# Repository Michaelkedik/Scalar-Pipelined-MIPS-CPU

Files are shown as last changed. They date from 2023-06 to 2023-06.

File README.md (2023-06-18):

# Scalar Pipelined MIPS CPU Architecture

In this project I designed a Scalar Pipelined MIPS CPU that was executed on an altera board.
The CPU Core is capable of performing a variety of instructions from a given MIPS instruction set.
The architecture includes a MIPS ISA compatible CPU with data and program memory for hosting data and code and a standard MIPS register file. 
The top level and the MIPS core are structural and a single clock is used in the design.
In addition, the architecture includes hazard detection unit, forwarding unit, flushing and a single delay slot support.  
The figure below illustrates the design.  



## Description

The repositories in this project serve the following purposes:

**VHDL:** This repository contains VHDL codes for the top entity and components. These codes can be compiled using ModelSim and Quartus.

**DOC:** This repository contains project documentation and a README file that provides an explanation of the VHDL files' purpose.

**CODE:** This repository contains assembly code used for verifying the design's functionality.

**TB:** This repository contains Testbench files that were used for ModelSim verification of the design.

**SIM:** This repository contains ".do" files used for ModelSim simulation.

**QUARTUS:** This repository contains project files such as ".sof," SDC, and STP files, which are used for Quartus compilation and verification of the design.

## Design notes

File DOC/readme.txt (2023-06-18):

1)MIPS - The top entity, Synchronizes all the other components
2)IFETCH - Get the instruction and advance the PC according to the relevant adress
3)IDECODE - Decode the instruction and read and write from the register file
4)DMEMORY- Read or write from the data memory
5)EXECUTE- Performs all the logic or arithmetic actions
6)CONTROL - Produces the control signals that are needed for the instructions to be executed
7)HDU - Hazard Detection Unit, Detects dependencies between instructions and raise a stall signal when needed
8)FU - Forwarding Unit, Detects when forwarding is needed and raises control signals that are needed to decide which data will be used
	   in the ALU

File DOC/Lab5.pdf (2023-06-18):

# מעבדת ארכיטקטורת מעבדים מתקדמת ומאיצי חומרה

# דו"ח מעבדה 5

# מיכאל קדיק 316645415 עמית ניסני 205664345

## תיאור המ עבדה

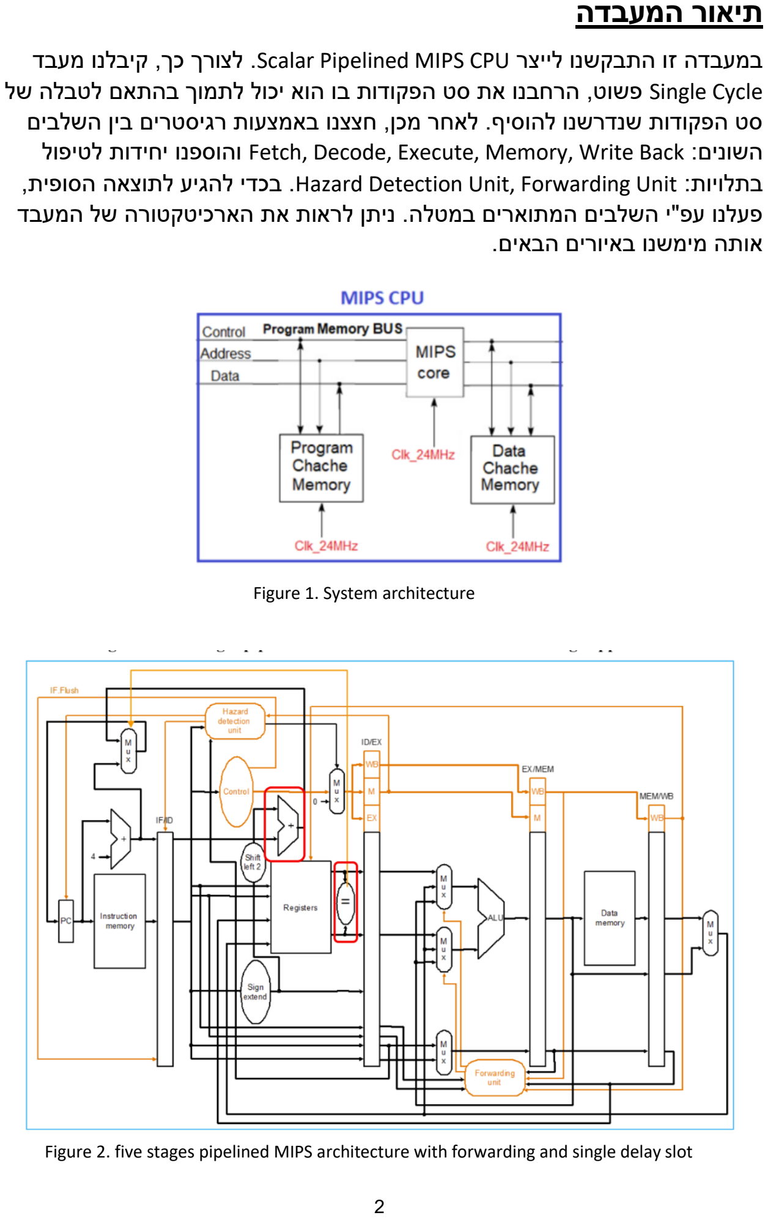
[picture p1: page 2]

במעבדה זו התבקשנו לייצר CPU MIPS Pipelined Scalar. לצורך כך, קיבלנו מעבד Cycle Single פשוט, הרחבנו את סט הפקודות בו הוא יכול לתמוך בהתאם לטבלה של סט הפקודות שנדרשנו להוסיף. לאחר מכן, חצצנו באמצעות רגיסטרים בין השלבים
לטיפול | ות | יחיד | והוספנו | Fetch, Decode, Execute, Memory, Write Back : | השונים
בתלויות: Unit Forwarding ,Unit Detection Hazard. בכדי להגיע לתוצאה הסופית, פעלנו עפ"י השלבים המתוארים במטלה. ניתן לראות את הארכיטקטורה של המעבד אותה מימשנו באיורים הבאים.

Figure 1. System architecture

Figure 2. five stages pipelined MIPS architecture with forwarding and single delay slot

כמו כן, הוספנו במעטפת החיצונית יציאות בכדי שנוכל לעקוב אחרי התוכנית באופן הבא:

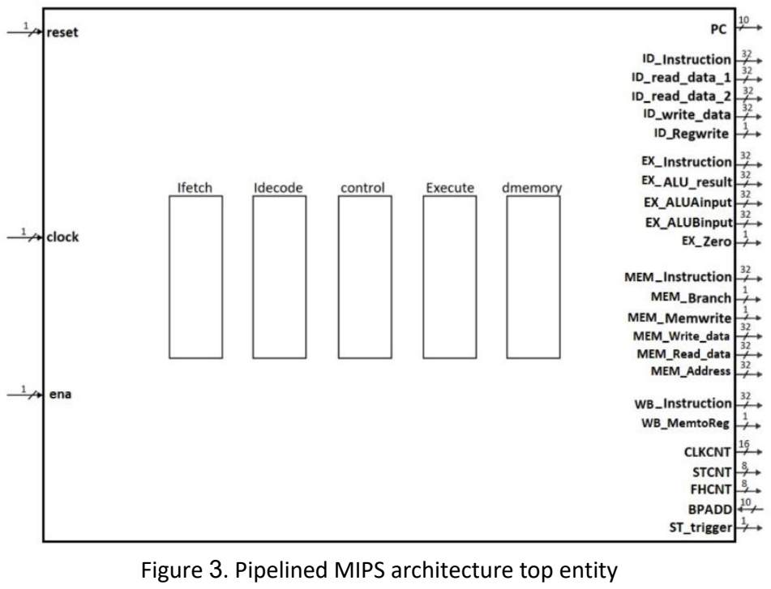
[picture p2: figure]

בכדי ליצור את המעבד המצוין למעלה, השתמשנו ברכיבי חומרה עליהם נפרט באיורים הבאים.

Figure 3. Pipelined MIPS architecture top entity

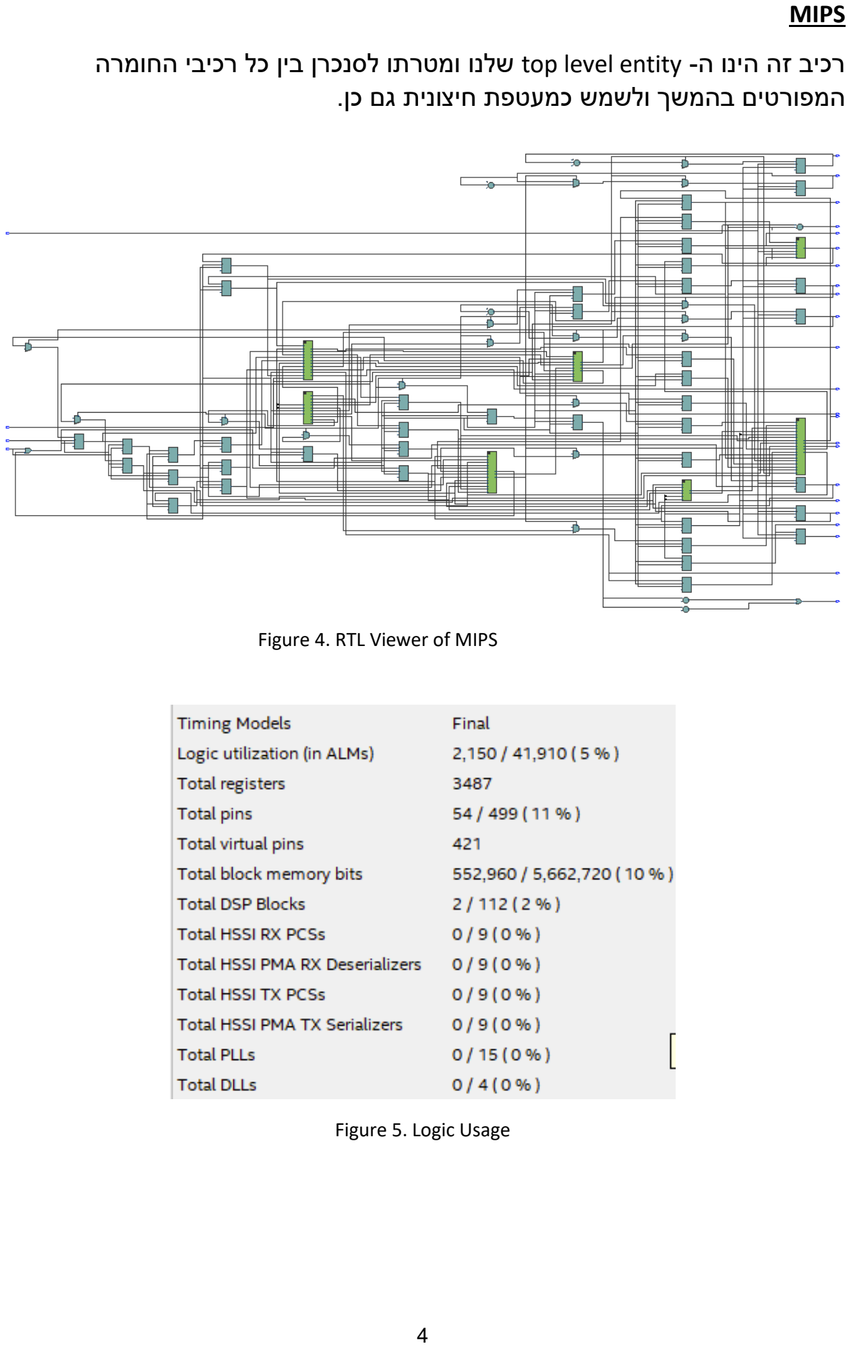
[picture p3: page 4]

MIPS

רכיב זה הינו ה- entity level top שלנו ומטרתו לסנכרן בין כל רכיבי החומרה המפורטים בהמשך ולשמש כמעטפת חיצונית גם כן.

Figure 4. RTL Viewer of MIPS

Figure 5. Logic Usage

IFETCH

תפקידו של רכיב זה הוא להביא את הפקודה שיש לבצע ולקדם את ה-pc לפקודה הבאה )שאינה בהכרח הפקודה העוקבת, כמו למשל אם יש jump).

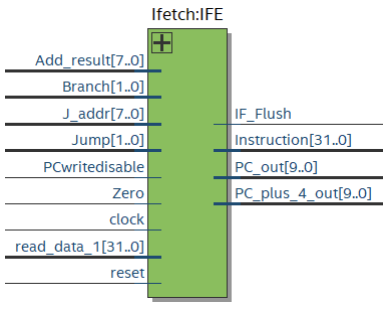
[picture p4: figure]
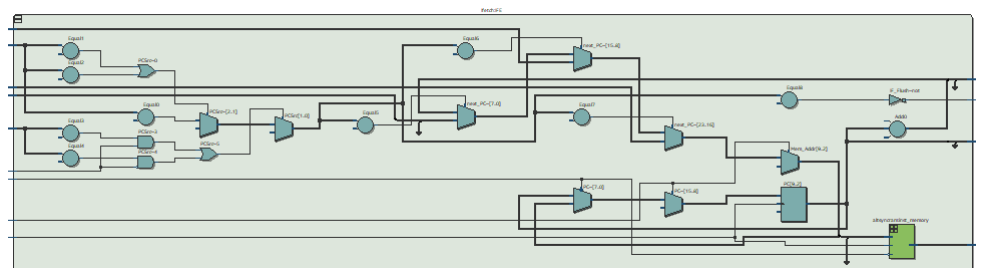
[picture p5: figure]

Name | Direction | Size | Functionality
clock | IN | 1 | שעון
reset | IN | 1 | אתחול
Add_result | IN | 8 | הסתעפות כתובת
| | | משמש לפקודת קפיצה 32 IN 1_data_read
J_addr | IN | 8 | קפיצה כותבת
Branch | IN | 2 | בקרה
Jump | IN | 2 | בקרה
Zero | IN | 1 | בקרה
| | | משמש לעיכוב הפקודות 1 IN PCwritedisable
| | | פקודה לביצוע 32 OUT Instruction
| | | כתובת של פקודה הבאה 10 OUT out_4_plus_PC
| | | כתובת של פקודה נוכחית 10 OUT out_PC
| | | בקרה לריקון הרגיסטר 1 OUT Flush_IF

Figure 6. Graphical description of IFETCH

Figure 7. RTL Viewer of IFETCH

Table 1. Port Table of IFETCH

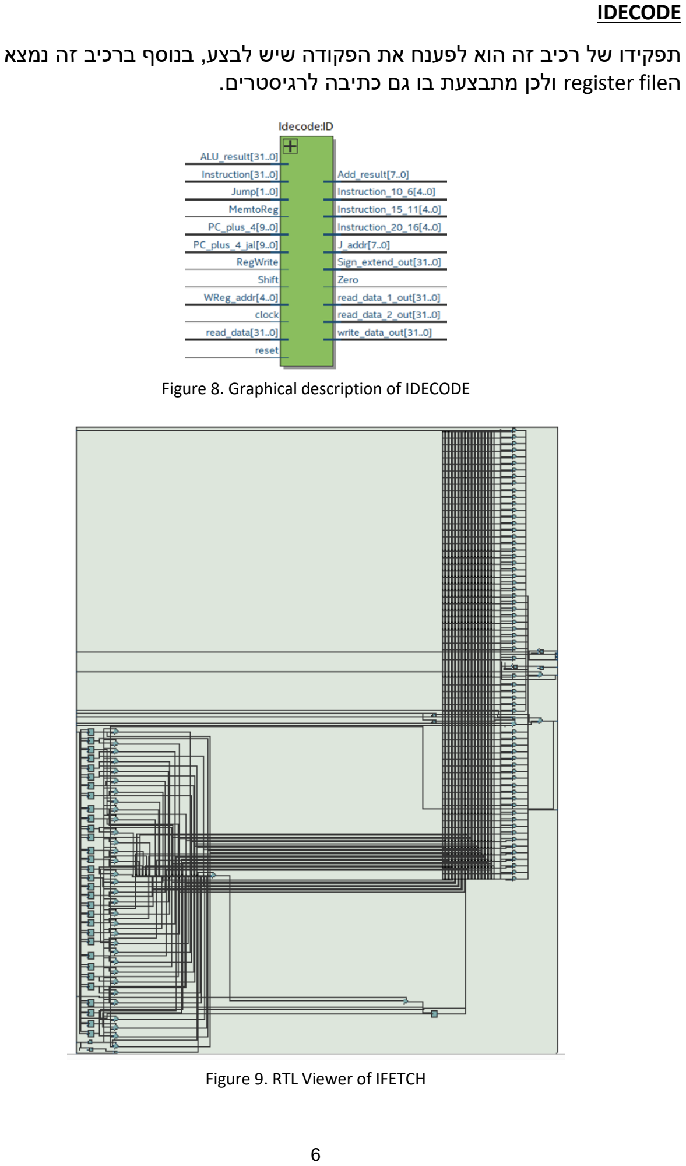
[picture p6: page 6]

IDECODE

תפקידו של רכיב זה הוא לפענח את הפקודה שיש לבצע , בנוסף ברכיב זה נמצא הfile register ולכן מתבצעת בו גם כתיבה לרגיסטרים.

Figure 8. Graphical description of IDECODE

Figure 9. RTL Viewer of IFETCH

Name | Direction | Size | Functionality
clock | IN | 1 | שעון
reset | IN | 1 | אתחול
| | | הפקודה הנוכחית לפענוח 32 IN Instruction
read_data | IN | 32 | המידע בכתיבה לרגיסטרים
ALU_result | IN | 32 | ALU -ב הפעולה תוצאת
RegWrite | IN | 1 | בקרה
MemtoReg | IN | 1 | בקרה
Jump | IN | 2 | בקרה
Shift | IN | 1 | בקרה
PC_plus_4_jal | IN | 10 | המידע לכתיבה לרגיסטר במידה ויש jal
PC_plus_4 | IN | 10 | כתובת של הפקודה הבאה לביצוע
WReg_addr | IN | 5 | כתובת המעידה לאיזה רגיסטר יש לכתוב
read_data_1_out | OUT | 32 | 1 מרגיסטר המידע
read_data_2_out | OUT | 32 | 2 מרגיסטר המידע
write_data_out | OUT | 32 | לרגיסטרים שנכתב המידע
Sign_extend_out | OUT | 32 | המידע בשדה הimmidiate מורחב
| | | ביטים 16-20 בפקודה 5 OUT 16_20_Instruction
| | | ביטים 11-15 בפקודה 5 OUT 11_15_Instruction
| | | ביטים 6-10 בפקודה 5 OUT 6_10_Instruction
Add_result | OUT | 8 | הסתעפות כתובת
Zero | OUT | 1 | בקרה
J_addr | OUT | 8 | קפיצה כתובת

Table 2. Port Table of IDECODE

CONTROL

תפקידו של רכיב זה הוא לייצר את קווי הבקרה בהתאם לפקודה הנוכחית.

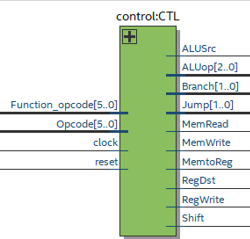
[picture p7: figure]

Figure 10. Graphical description of CONTROL

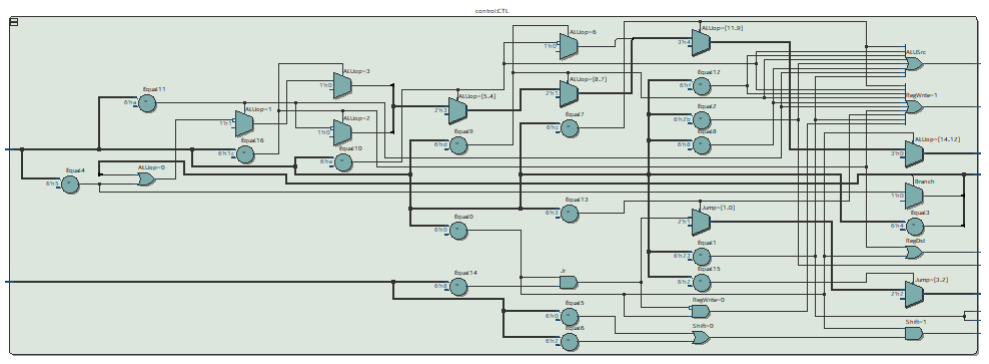
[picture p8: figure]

Figure 11. RTL Viewer of CONTROL

Name | Direction | Size | Functionality
clock | IN | 1 | שעון
reset | IN | 1 | אתחול
| | | ביטים 26-31 בפקודה 6 IN Opcode
Function_opcode | IN | 6 | בפקודה 0-5 ביטים
RegDst | OUT | 1 | קו בקרה לבחירת כתובת יעד הכתיבה לרגיסטר
ALUSrc | OUT | 1 | קו בקרה הבורר איזה מידע יכנס לכניסה B ב-ALU
MemtoReg | OUT | 1 | קו בקרה הבורר בין המידע שיכתב לתוך הרגיסטרים )מהזכרון או מה-ALU)
RegWrite | OUT | 1 | קו בקרה הבורר את כתובת הרגיסטר לכתיבה
MemRead | OUT | 1 | קו בקרה המבחין האם יש לקרוא מהזכרון
MemWrite | OUT | 1 | קו בקרה המבחין האם יש לכתוב לזכרון
Shift | OUT | 1 | קו בקרה המבחין האם יש פעולת shift
Jump | OUT | 2 | קו בקרה המבחין האם יש פעולת קפיצה
Branch | OUT | 2 | קו בקרה המבחין האם יש פעולת הסתעפות
ALUop | OUT | 3 | קו בקרה הבורר איזה פעולה יש לעשות ב-ALU

Table 3. Port Table of CONTROL

EXECUTE

תפקידו של רכיב זה הוא ביצוע הפעולות הנדרשות בכדי לבצע את הפקודה.

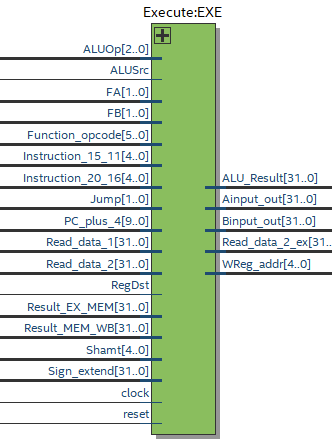
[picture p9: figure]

Figure 12. Graphical description of EXECUTE

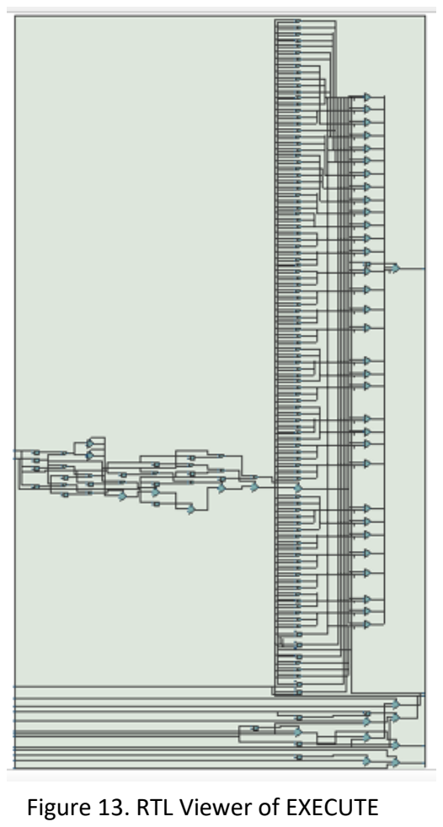
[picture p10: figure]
Figure 13. RTL Viewer of EXECUTE

Name | Direction | Size | Functionality
clock | IN | 1 | שעון
reset | IN | 1 | אתחול
Read_data_1 | IN | 32 | 1 מרגיסטר מידע
Read_data_2 | IN | 32 | 2 מרגיסטר מידע
Sign_extend | IN | 32 | מידע משדה הimmidiate מורחב
| | | ביטים 0-5 של הפקודה 6 IN opcode_Function
ALUSrc | IN | 1 | בקרה
FA | IN | 2 | בקרה
FB | IN | 2 | בקרה
ALUOp | IN | 3 | בקרה
Result_EX_MEM | IN | 32 | מידע מרגיסטר בהמשך למטרת forwarding
Result_MEM_WB | IN | 32 | מידע מרגיסטר בהמשך למטרת forwarding
PC_plus_4 | IN | 10 | כתובת של הפקודה הבאה לביצוע
Jump | IN | 2 | בקרה
RegDst | IN | 1 | בקרה
| | | ביטים 16-20 בפקודה 5 IN 16_20_Instruction
| | | ביטים 11-15 בפקודה 5 IN 11_15_Instruction
| | | ביטים 6-10 בפקודה 5 IN Shamt
Ainput_out | OUT | 32 | מידע שנכנס לכניסה A ב-ALU
Binput_out | OUT | 32 | מידע שנכנס לכניסה B ב-ALU
ALU_Result | OUT | 32 | ALU -ה תוצאת
Read_data_2_ex | OUT | 32 | 2 מרגיסטר מידע
| | | כתובת כתיבה לרגיסטרים 5 OUT addr_WReg

Table 4. Port Table of EXECUTE

DMEMORY

תפקידו של רכיב זה הוא לבצע קריאה מהזכרון או כתיבה לזכרון.

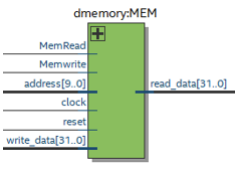
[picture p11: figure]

Figure 14. Graphical description of DMEMORY

Figure 15. RTL Viewer of EXECUTE

Name | Direction | Size | Functionality
clock | IN | 1 | שעון
reset | IN | 1 | אתחול
| | | כתובת כתיבה לזכרון 10 IN address
| | | מידע שנכתב לזכרון 32 IN data_write
MemRead | IN | 1 | בקרה
Memwrite | IN | 1 | בקרה
| | | מידע שיוצא מהזכרון 32 OUT data_read

Table 5. Port Table of DMEMORY

HDU

תפקידו של רכיב זה הוא לזהות תלויות בין פקודות ולבצע השהיה במקרה הצו רך.

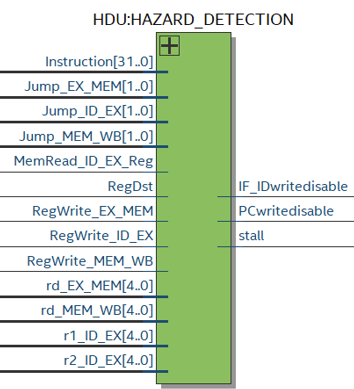
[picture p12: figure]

Figure 16. Graphical description of HDU

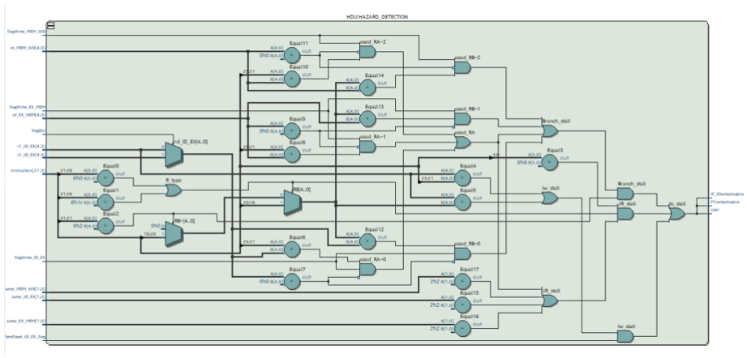
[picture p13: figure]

Figure 17. RTL Viewer of HDU

Name | Direction | Size | Functionality
| | | פקודה לביצוע 32 IN Instruction
r1_ID_EX | IN | 5 | 1 רגיסטר
r2_ID_EX | IN | 5 | 2 רגיסטר
rd_EX_MEM | IN | 5 | רגיסטר המטרה של פקודה קודמת שנמצאת ב-EXECUTE
rd_MEM_WB | IN | 5 | רגיסטר המטרה של פקודה קודמת שנמצאת ב-WB
Jump_ID_EX | IN | 2 | בקרה
Jump_EX_MEM | IN | 2 | בקרה
Jump_MEM_WB | IN | 2 | בקרה
RegWrite_ID_EX | IN | 1 | בקרה
RegWrite_EX_MEM | IN | 1 | בקרה
RegWrite_MEM_WB | IN | 1 | בקרה
RegDst | IN | 1 | בקרה
MemRead_ID_EX_Reg | IN | 1 | בקרה
PCwritedisable | OUT | 1 | אות בקרה שמתפקידו לעכב את ה- PC
IF_IDwritedisable | OUT | 1 | אות בקרה שתפקידו לעכב את רגיסטר ID_IF
stall | OUT | 1 | אות בקרה שתפקידו לעכב את המעבד

Table 6. Port Table of HDU

FU

תפקידו של רכיב זה הוא לזהות תלויות שניתן לפתור ללא השהיה ובמקרה הצורך להעביר את המידע משלב מתקדם יותר אל שלב ה-Execute.

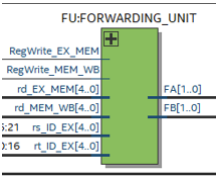
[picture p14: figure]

Figure 18. Graphical description of FU

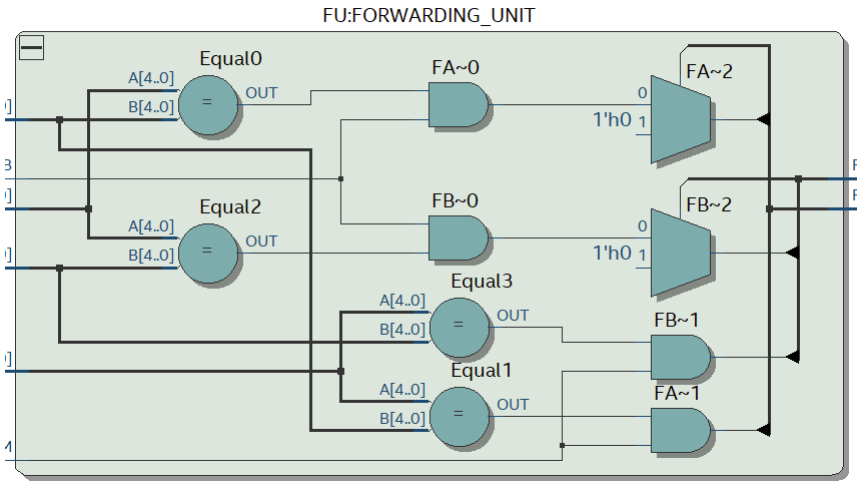
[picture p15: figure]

Figure 18. RTL Viewer of FU

כמו כן, בדקנו את ה- fmax ואת המסלול הארוך ביותר עבור מימוש ה cycle single ועבור המימוש הסופי. ניתן לראות אותם באיורים הבאים.

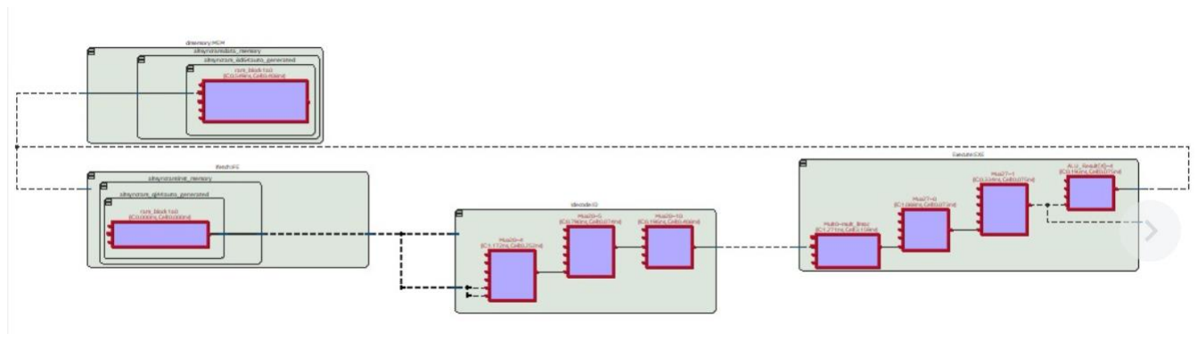
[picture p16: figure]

ניתן לראות כי המסלול הקריטי עובר בכל הרכיבים, כצפוי ממעבד Cycle Single.

Name | Direction | Size | Functionality
rs_ID_EX | IN | 5 | rs רגיסטר
rt_ID_EX | IN | 5 | rd רגיסטר
rd_EX_MEM | IN | 5 | רגיסטר מטרה משלב ה-MEM
rd_MEM_WB | IN | 5 | רגיסטר מטרה משלב ה-WB
RegWrite_EX_MEM | IN | 1 | בקרה
RegWrite_MEM_WB | IN | 1 | בקרה
FA | OUT | 2 | קו בקרה הבורר מה יכנס לכניסה A ב- ALU
FB | OUT | 2 | קו בקרה בורר מה יכנס לכניסה B ב-ALU

Table 7. Port Table of FU

Figure 19. Fmax of the Single Cycle MIPS

Figure 20. Critical Path of the Single Cycle MIPS

ניתן להבחין כי המסלול הקריטי מתחיל בשלב ה-DECODE ונגמר בשלב ה-FETCH. דבר זה נובע מפקודות ההסתעפות בהן מתבצעת החלטה בשלב ה- FETCH על סמך חישובים שמתבצעים ב DECODE. זוהי הפעולה היחידה שאין בה חציצה בין השלבים ולכן הגיוני שזה יהיה המסלול הארוך ביותר.

בכדי לבדוק את נכונות המימוש שלנו וש אכן המעבד מבצע את כל הפקודות כנדרש וכל רכיבי החומרה מבצעים את תפקידם כתבנו מספר תוכניות אסמבלי ובדקנו אותן באמצעות הModelsim.

Figure 21. Fmax of the Pipelined MIPS

Figure 22. Critical Path of the Pipelined MIPS

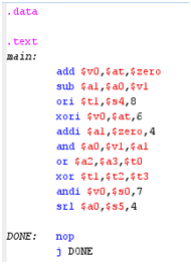
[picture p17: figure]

Figure 23. First assembly program

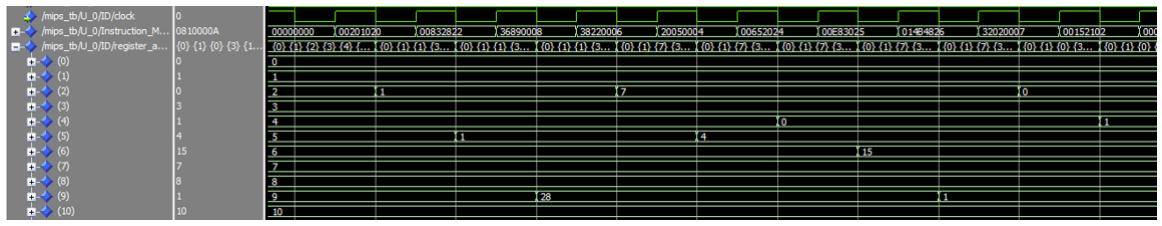
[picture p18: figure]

בתוכנית זו בדקנו ששלל הפקודות האריתמטיו ת והלוגיות עובדות כראוי, ניתן לראות שהתוצאות שנכתבות לרגיסטרים אכן נכונות כמצופה.

כמו כן, הוספנו תלויות בין הפקודות השונות שניתנות לטיפול באמצעות forwarding. ניתן לראות זאת באיור הבא.

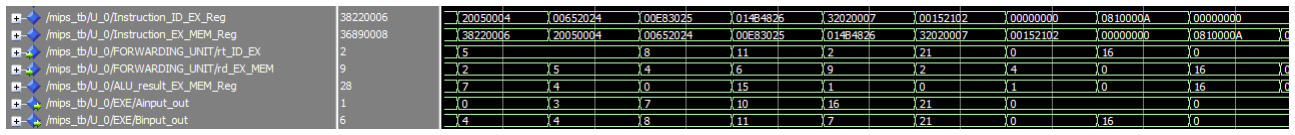
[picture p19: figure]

באיור זה ניתן להבחין בforwarding בשני מחזורי השעון הראשונים. ישנה פקודה )and )ש צריכה לקרוא ערך ברגיסטר ש פקודה קודמת )addi )כותבת אליו. ניתן לראות שהערך שנכנס לכניסה B של ה- ALU כאשר פקודת ה-and נמצאת ב- EXECUTE הוא התוצאה של פקודת ה- andi.

כמו כן, ניתן לראות את המעבר של פקודה בין הרגיסטרים השונים בפייפליין באיור הבא.

Figure 24. First assembly program results

Figure 25. First assembly program forwarding

Figure 26. First assembly program instructions

בנוסף, כתבנו תוכנית אסמבלי נוספת שבה בדקנו שאכן ההסתעפויות ופקודות הshift עובדות כמו שצריך. כמו כן, בדקנו שאכן מתבצע stall ו -flush בהתאם לצורך. ניתן לראות אותה ואת התוצאות באיורים הבאים.

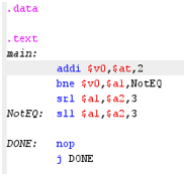
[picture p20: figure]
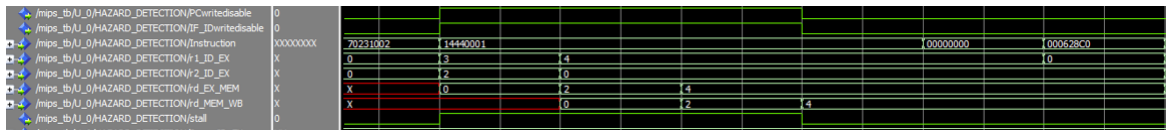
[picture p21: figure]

ניתן להבחין כי אכן כאשר נכנסת פקודת ההסתעפות אל ה-Unit Detection Hazard מצבצע stall ומיד לאחריו מתבצע flush מכיוון שצריך להסתעף. כמו כן, ניתן לראות שלאחר ה-flush התוכנית ממשיכה מהפקודה הנכונה.

כמו כן, התבקשנו לכתוב תוכנית אסמבלי שמבצעת חיבור מטריצות בהתאם לפסאודו-קוד הבא:

Figure 27. Second assembly program

Figure 28. Second assembly program results

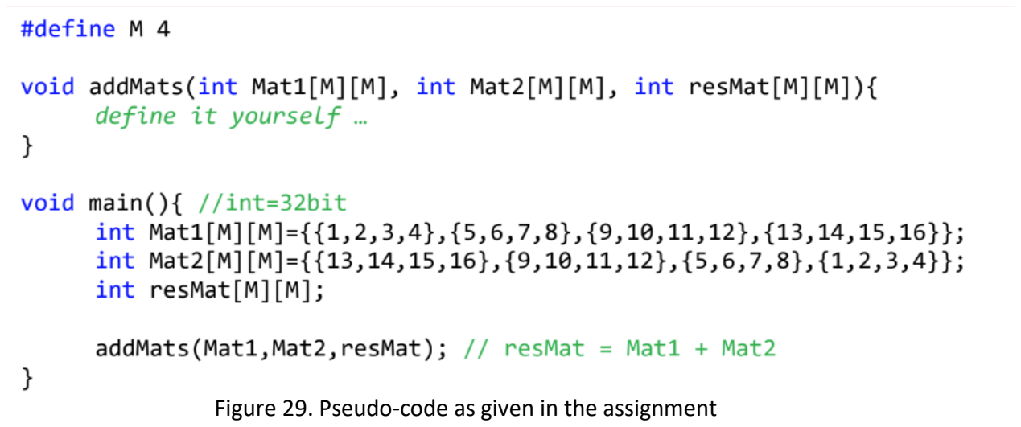
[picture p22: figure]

Figure 29. Pseudo-code as given in the assignment

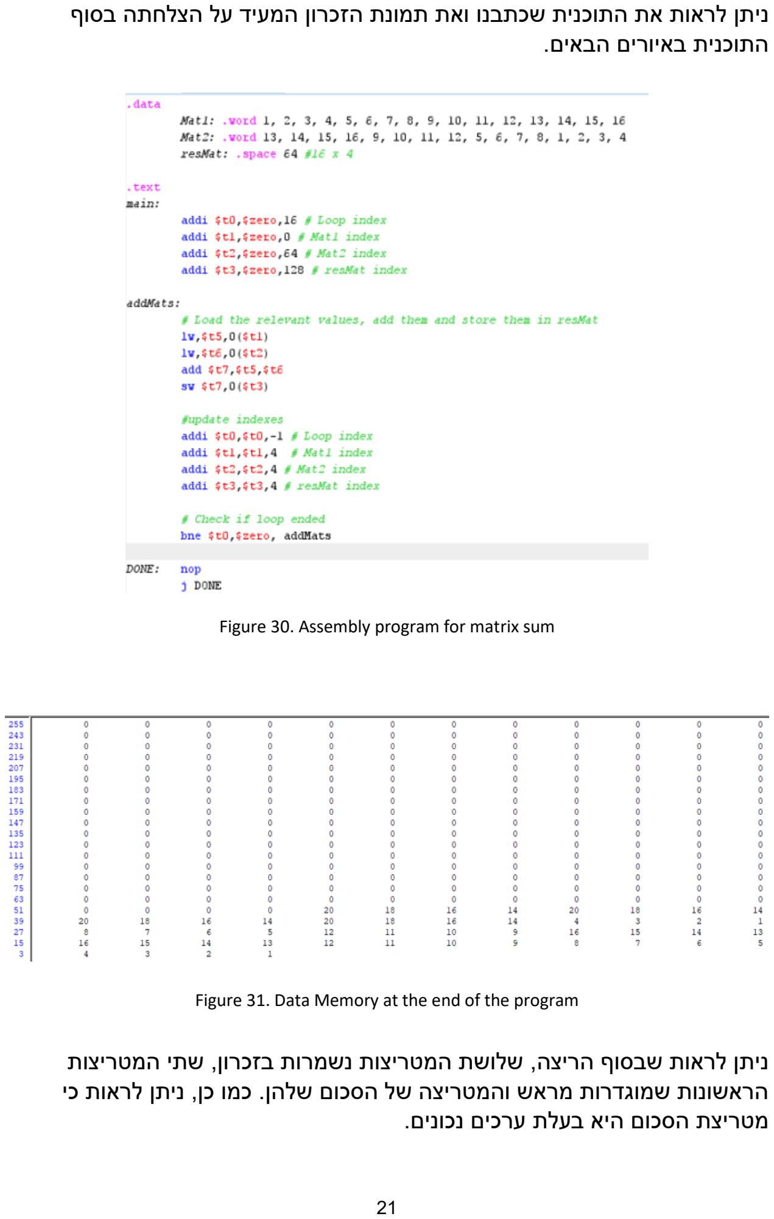
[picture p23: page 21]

ניתן לראות את התוכנית שכתבנו ואת תמונת הזכרון המעיד על הצלחתה בסוף התוכנית באיורים הבאים.

ניתן לראות שבסוף הריצה, שלושת המטריצות נשמרות בזכרון , שתי המטריצות הראשונות שמוגדרות מראש והמטריצה של הסכום שלהן. כמו כן, ניתן לראות כי מטריצת הסכום היא בעלת ערכים נכונים.

Figure 30. Assembly program for matrix sum

Figure 31. Data Memory at the end of the program

בנוסף, בדקנו את נכונות המימוש שלנו באמצעות הTap Signal ב- Quartus. ניתן לראות את התוצאות באיור הבא.

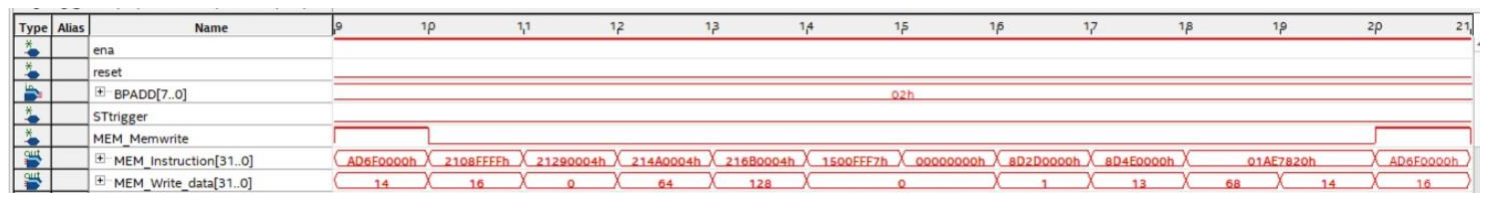
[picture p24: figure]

ניתן לראות שכאשר פקודת ה-sw מגיעה אל שלב ה-MEMORY, אכן יוצא הערך הנכון ב – data_Write_MEM, כמו כן עולה קו הבקרה Memwrite_MEM ולכן אנו מניחים שהערך גם נכנס לזכרון. מכיוון שאין לנו דרך לצפות בזכרון ב- Quartus לא יכלנו לוודא זאת.

בנוסף, הוספנו רגיסטרים שסופרים את כמות מחזורי השעון, stall ו- flush שהיו במהלך התוכנית. ניתן לראות את הערכים שלהם בסוף התוכנית באיור הבא.

ניתן לראות את ערכי הרגיסטרים בסוף התוכנית: מספר מחזורי השעון הוא ,180 מספר ה- stall הוא 16 ומספר ה- flush הוא .15 בעזרת נתונים אלו, חישבנו את ה-IPC באופן הבא:

IPC =

CLKCNT − (STCNT + 4 + FHCNT ∗ dept)
CLKCNT | =

180 − (16 + 4 + 15 ∗ 1)
180 | = 0.806

Figure 32. Signal Tap Verification

Figure 33. Signal Tap counters values

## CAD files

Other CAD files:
Quartus/stp.stp
